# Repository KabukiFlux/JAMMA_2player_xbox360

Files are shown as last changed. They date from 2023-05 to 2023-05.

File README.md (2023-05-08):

<p align="center">
  <h1 align="center">JAMMA Xbox360 wired controller for RGBUNTU/PI/MiSTer<br>
  (cheap version, no protections)</h1>
</p>

## Table of contents

- [Description](#description)
- [Schematics](#schematics)
- [How to use](#how-to-use)
- [Bugs and feature requests](#bugs-and-feature-requests)
- [Copyright and license](#copyright-and-license)

## Description

This is intended to be a very cheap JAMMA 2 players board to USB adapter and <b> it was done during a live Twitch event (less than 4 hours)</b>.

It uses 2 pi-pico with 2 usb ports, one for the player 1 and other for the player 2, on the computer/raspberry/MiSTer side it will be automatically recognized as 2 Xbox360 wired controllers.

This board can be used as a JAMMA adapter or connected via the dirt cheap Molex KK254 connectors or the Aliexpress equivalent KF2510.

For the computer it can be connected via USB-B or the USB micro included on the PiPico

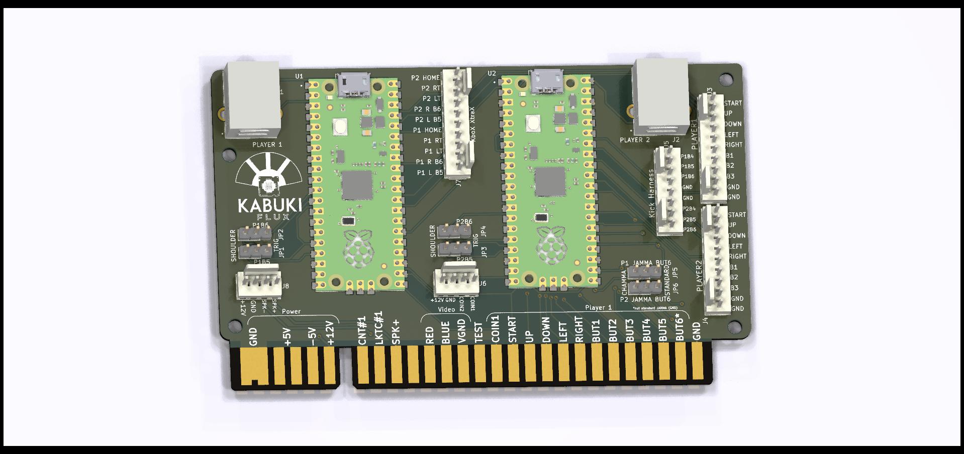
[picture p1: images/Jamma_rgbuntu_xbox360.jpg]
KiCAD_board_top


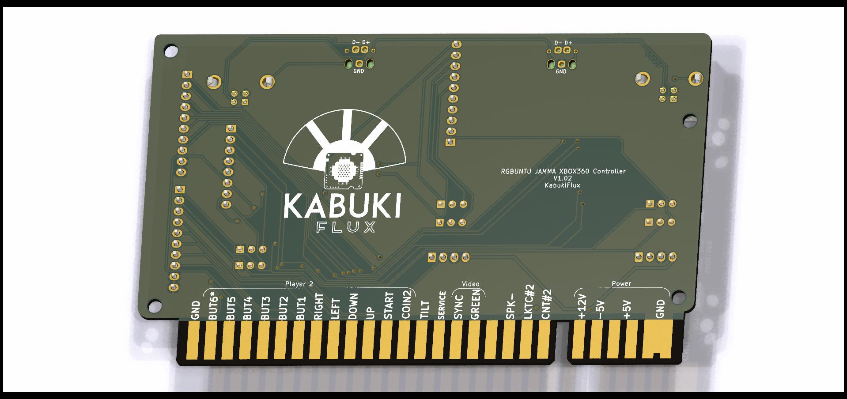
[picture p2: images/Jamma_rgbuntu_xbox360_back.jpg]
KiCAD_board_bottom


The software used for this board is the:

[FeralAI rp2040 xbox controller](https://github.com/FeralAI/GP2040)

now the project has become

[OpenStickCommunity GP2040-CE](https://github.com/OpenStickCommunity/GP2040-CE)

On the releases tab https://github.com/OpenStickCommunity/GP2040-CE/releases you can find the latest firmware GP2040-CE_X.X.X_Pico.uf2 to flash the pi pico

## Schematics

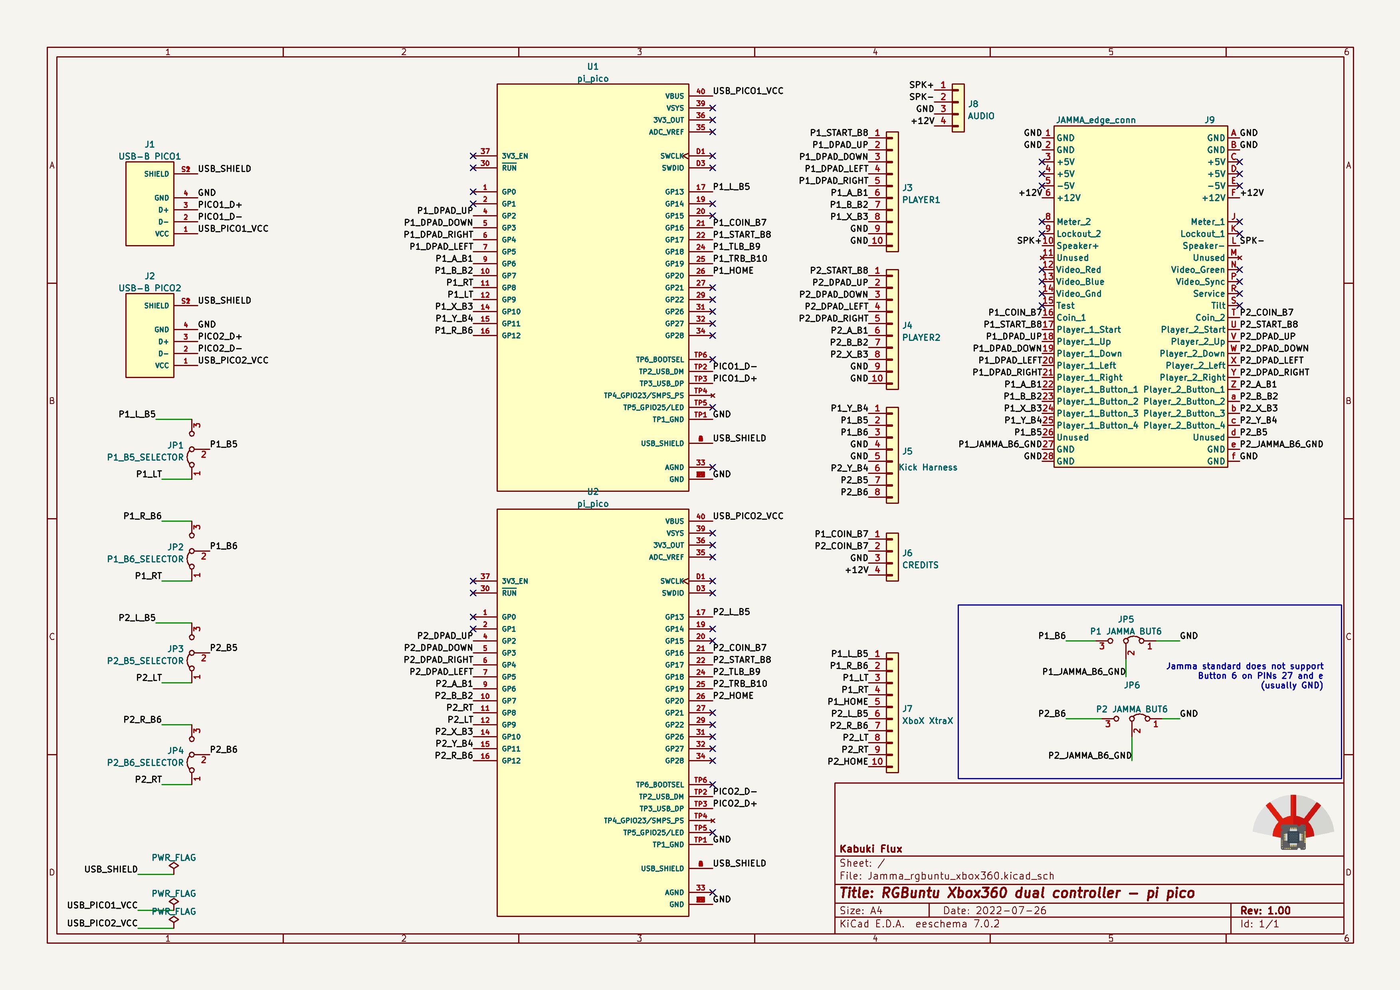
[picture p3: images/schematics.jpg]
Schematics


## How to use

1- Send to manufacture the board to JLCPCB or other PCB manufacturer. I recommend ENIG as the surface finish and Gold Fingers checked with 30º angle chamfer as well.

2- Get the components required, you can see here the Bill Of Materials [BOM](ibom.html)

3- Solder the components required by your setup (maybe you don't need audio input to the JAMMA edge or the Xtra Xbox buttons)

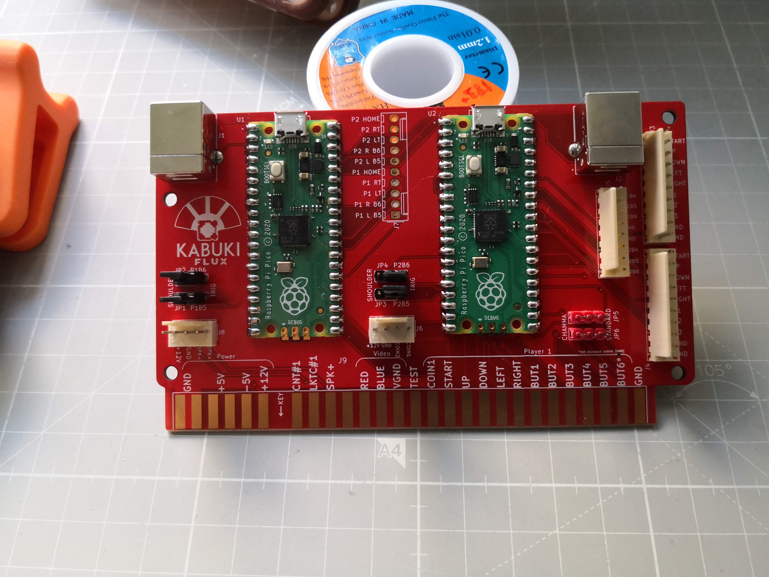
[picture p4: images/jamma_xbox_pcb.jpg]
Solder


4- On the back on the board if you want to use the USB-B connectors check that you have soldered correctly the test points called D+ and D-, it will solder directly into the test points of the PiPico the GND point is not required but recommended.

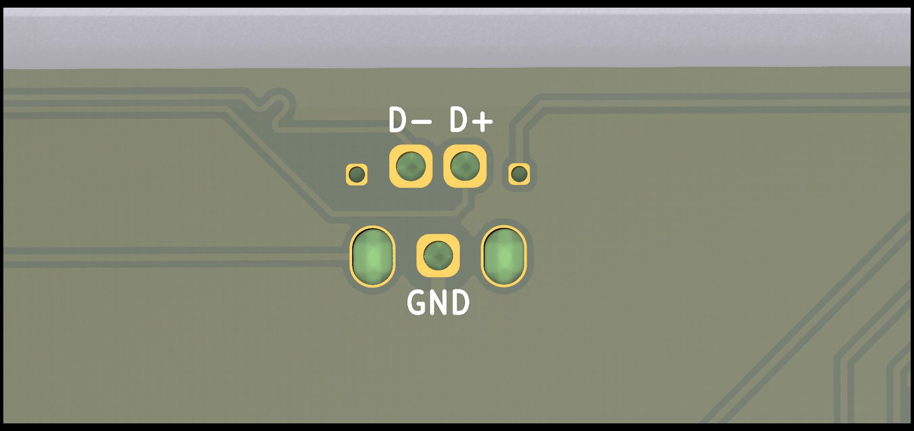
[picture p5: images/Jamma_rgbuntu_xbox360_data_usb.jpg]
Solder Usb


5- Ensure your Arcade Cabinet doesn't send 12v on the coin circuitry, a switch is only allowed here. (There are some converters, use Google)

6- Connect each PiPico to the PC and you will see a new USB drive unit appear, copy the file .uf2 from here https://github.com/OpenStickCommunity/GP2040-CE/releases into the PiPico (GP2040-CE_X.X.X_Pico.uf2) it will restart and will be recognized as a Xbox360 wired controller.

7- Connect to your arcade cabinet via JAMMA or Molex (if your JAMMA wiring is very damaged) and enjoy your PC/MiSTer/Pi setup.

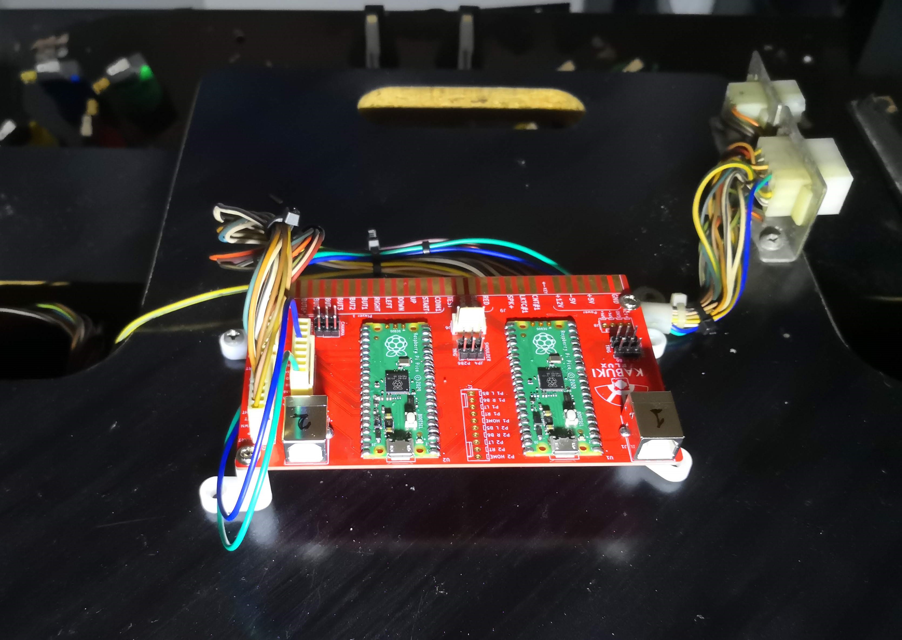
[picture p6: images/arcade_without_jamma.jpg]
Connect to Arcade Cabinet


8- If the 2nd player appears as the 1st player swap the USB cables.

### Mappings and jumpers

The default mapping is done to match the one on RGBuntu OS (15khz Ubuntu OS, use Google).

<b>If you are one of the RGBuntu developers: please, if possible, can you remap Player 2 on all systems as well, xD? (at the time of writing this only P1 is currently mapped by default)</b>.

You can see here the mapping as a Xbox360 controller (default .uf2) but everything is labeled on the silkscreen.

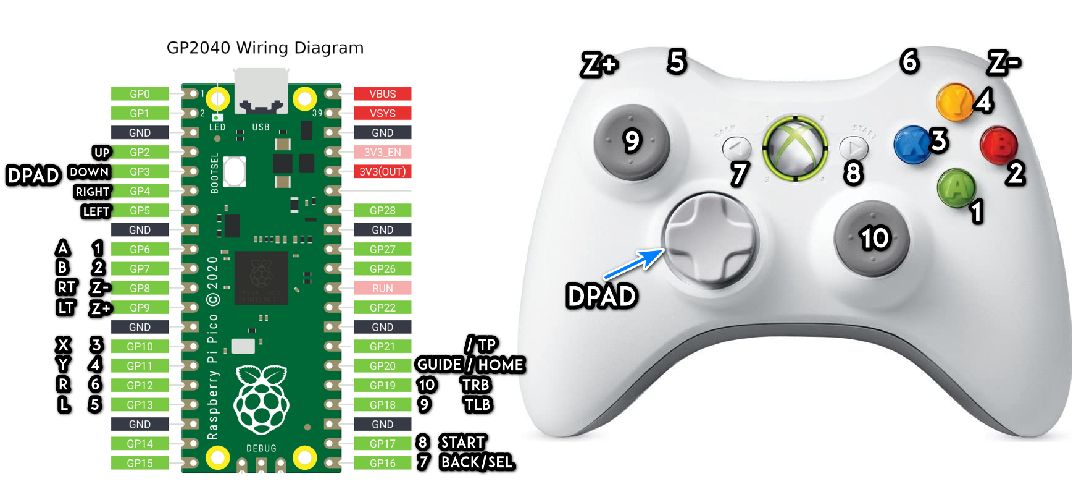
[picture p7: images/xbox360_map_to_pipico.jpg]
Xbox Mapping


- JP1, JP2, JP3 and JP4 choose the button 5 and 6 of each player to be mapped into the trigger or the shoulder buttons on the Xbox controller (I recommend the shoulder)

- JP5 and JP6 disable the button 6 of each player on the JAMMA edge to be compatible with the legacy JAMMA standard.

- J3 J4 and J5 are the Player 1, Player 2 and Kick Harness buttons respectively.

- J7 are non-standard used buttons just in case

- J6 is the dedicated coin connector, remember not to connect it if your coin mechanism sends 12vDC

- J8 is the dedicated audio input to send to the JAMMA edge in mono.

- <b>Read the documentation on https://github.com/OpenStickCommunity/GP2040-CE to see how to change the mappings in realtime like left or right stick and so.</b>

## Bugs and feature requests

Bugs and feature requests will be disabled as this is a dirty cheap example. If you want you can use it at your own risk.

### Errors

- To make it cheaper no overvoltage prevention or JAMMA wiring inductance protection has been included on the design.
- Audio speaker input has very short amperage path.

## Copyright and license

Code and documentation copyright KabukiFlux 2023. Code released under the [MIT License](https://github.com/KabukiFlux/JAMMA_2player_xbox360/blob/main/LICENSE).

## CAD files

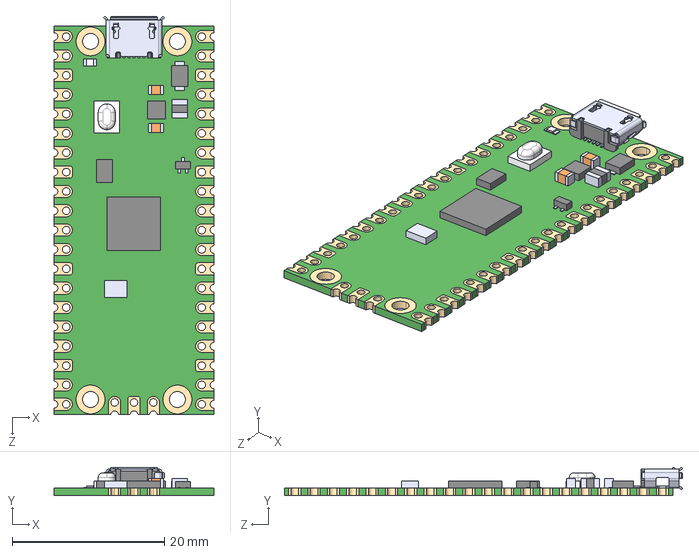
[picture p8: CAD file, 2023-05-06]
KiCAD/3D/pi_pico.step
21.0 x 3.73 x 52.3 mm

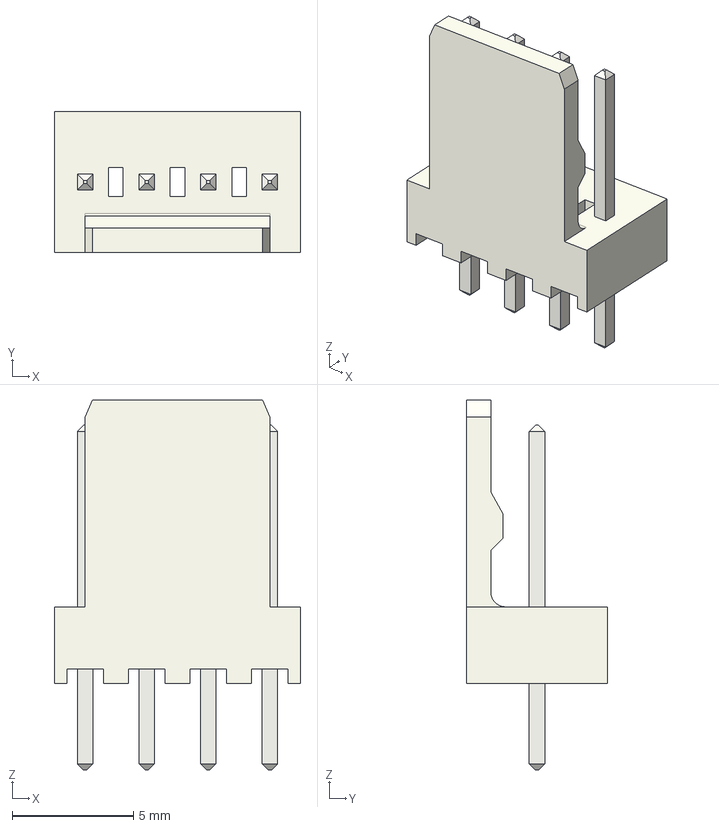
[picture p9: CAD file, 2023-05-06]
KiCAD/3D/Molex_KK-254_AE-6410-04A_1x04_P2.54mm_Vertical.step
10.2 x 5.80 x 15.3 mm

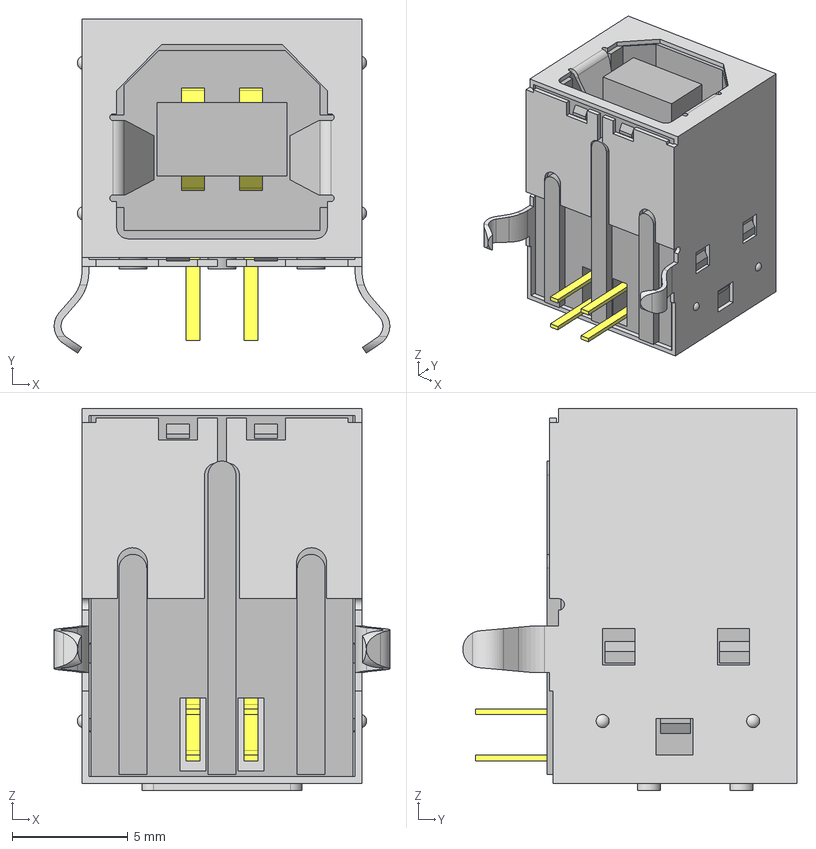
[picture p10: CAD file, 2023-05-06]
KiCAD/3D/USB-B-female.stp
14.5 x 14.4 x 16.5 mm
USB-B-S-TH_P
USB-B-S-B-TH_B
USB-B-S-TH_S

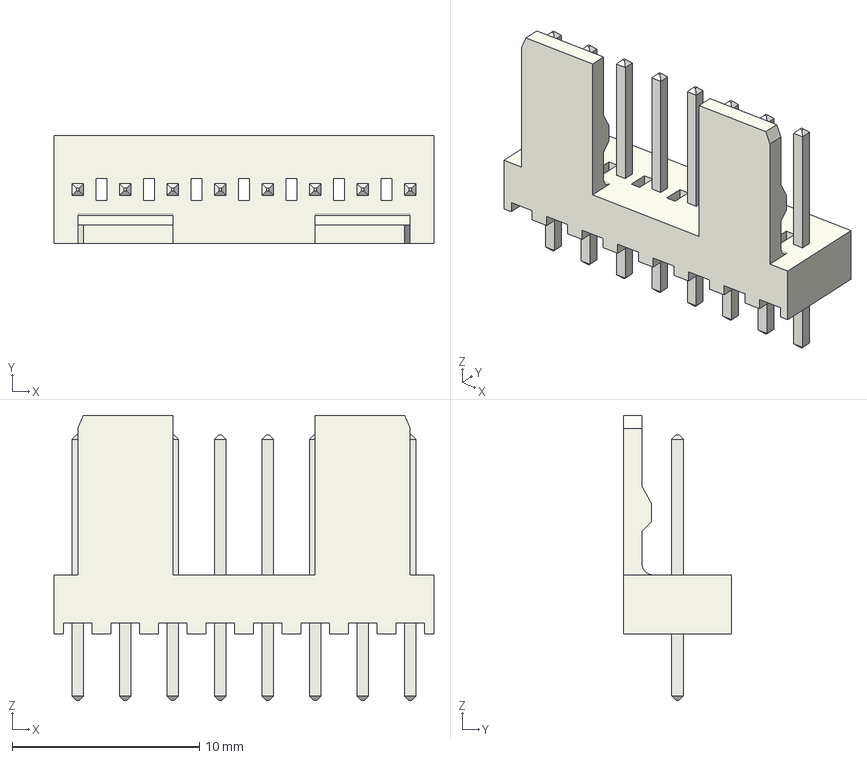
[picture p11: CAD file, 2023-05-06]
KiCAD/3D/Molex_KK-254_AE-6410-08A_1x08_P2.54mm_Vertical.step
20.3 x 5.80 x 15.3 mm

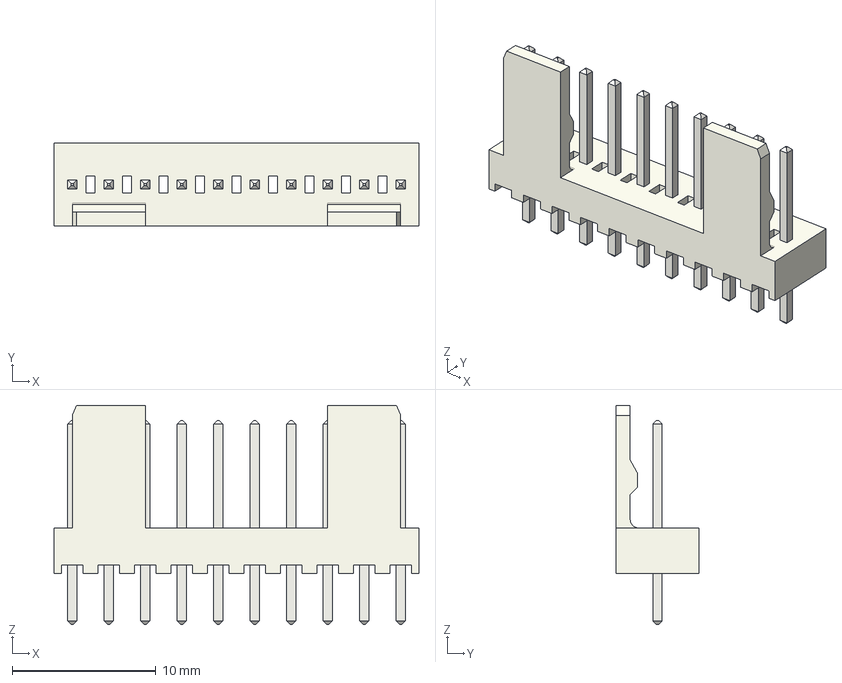
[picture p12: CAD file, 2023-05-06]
KiCAD/3D/Molex_KK-254_AE-6410-10A_1x10_P2.54mm_Vertical.step
25.4 x 5.80 x 15.3 mm

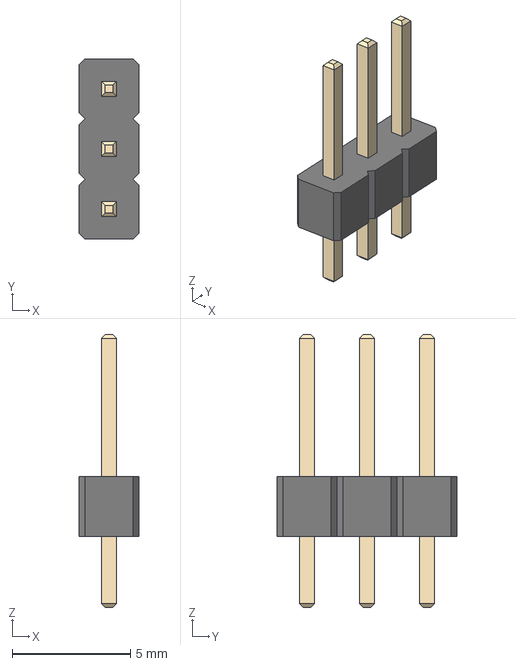
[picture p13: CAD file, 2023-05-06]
KiCAD/3D/PinHeader_1x03_P2.54mm_Vertical.step
2.54 x 7.62 x 11.5 mm

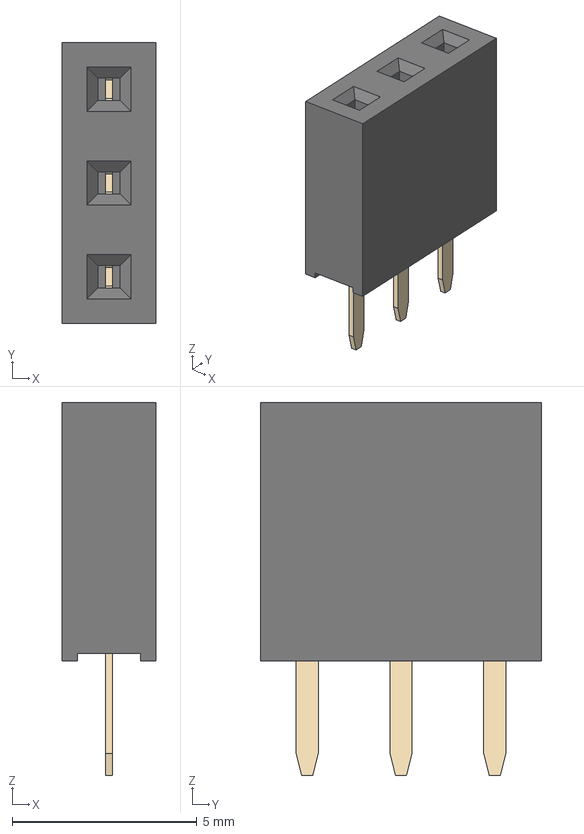
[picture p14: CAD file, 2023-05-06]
KiCAD/3D/PinSocket_1x03_P2.54mm_Vertical.step
2.54 x 7.62 x 10.1 mm

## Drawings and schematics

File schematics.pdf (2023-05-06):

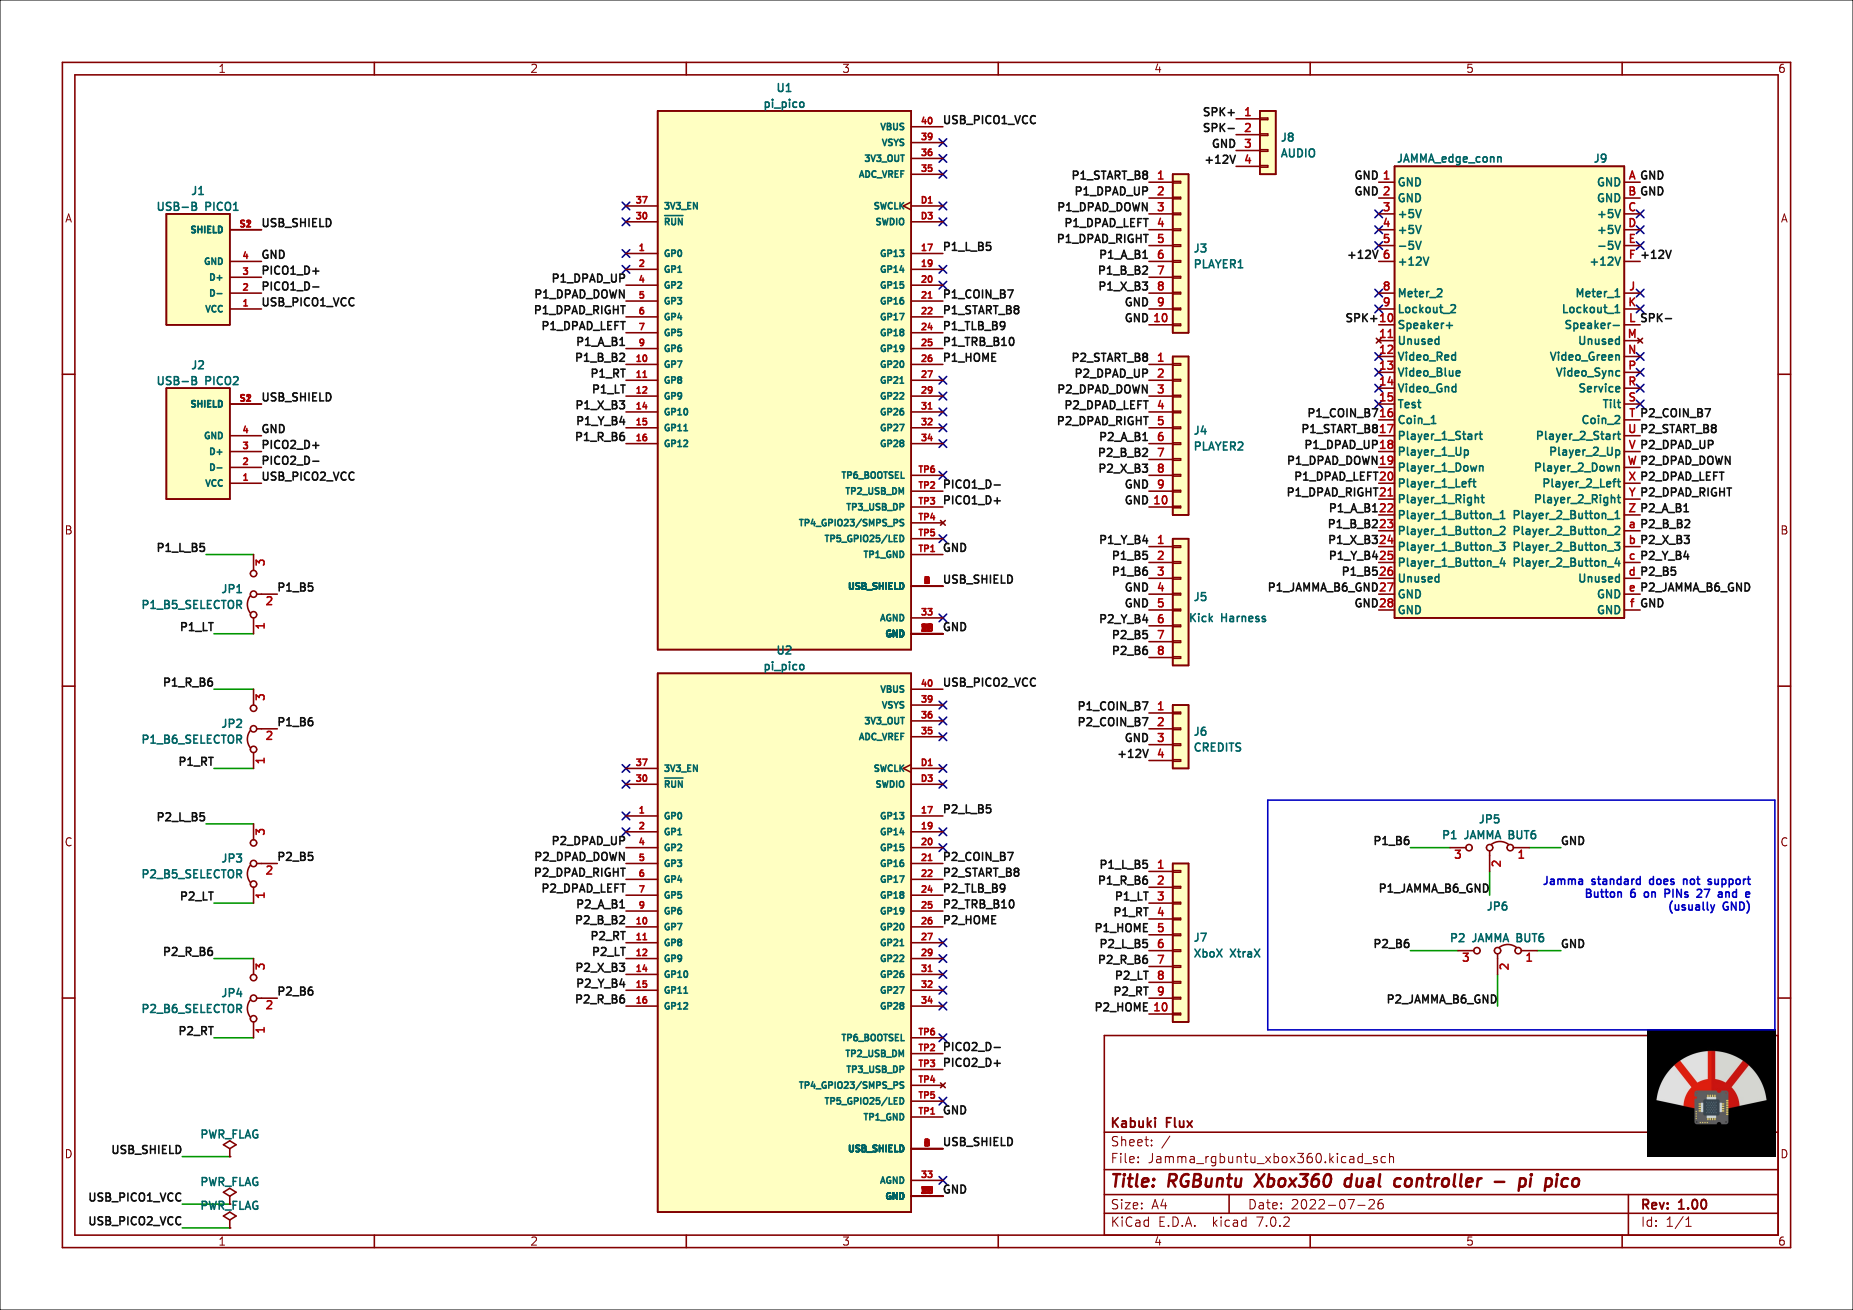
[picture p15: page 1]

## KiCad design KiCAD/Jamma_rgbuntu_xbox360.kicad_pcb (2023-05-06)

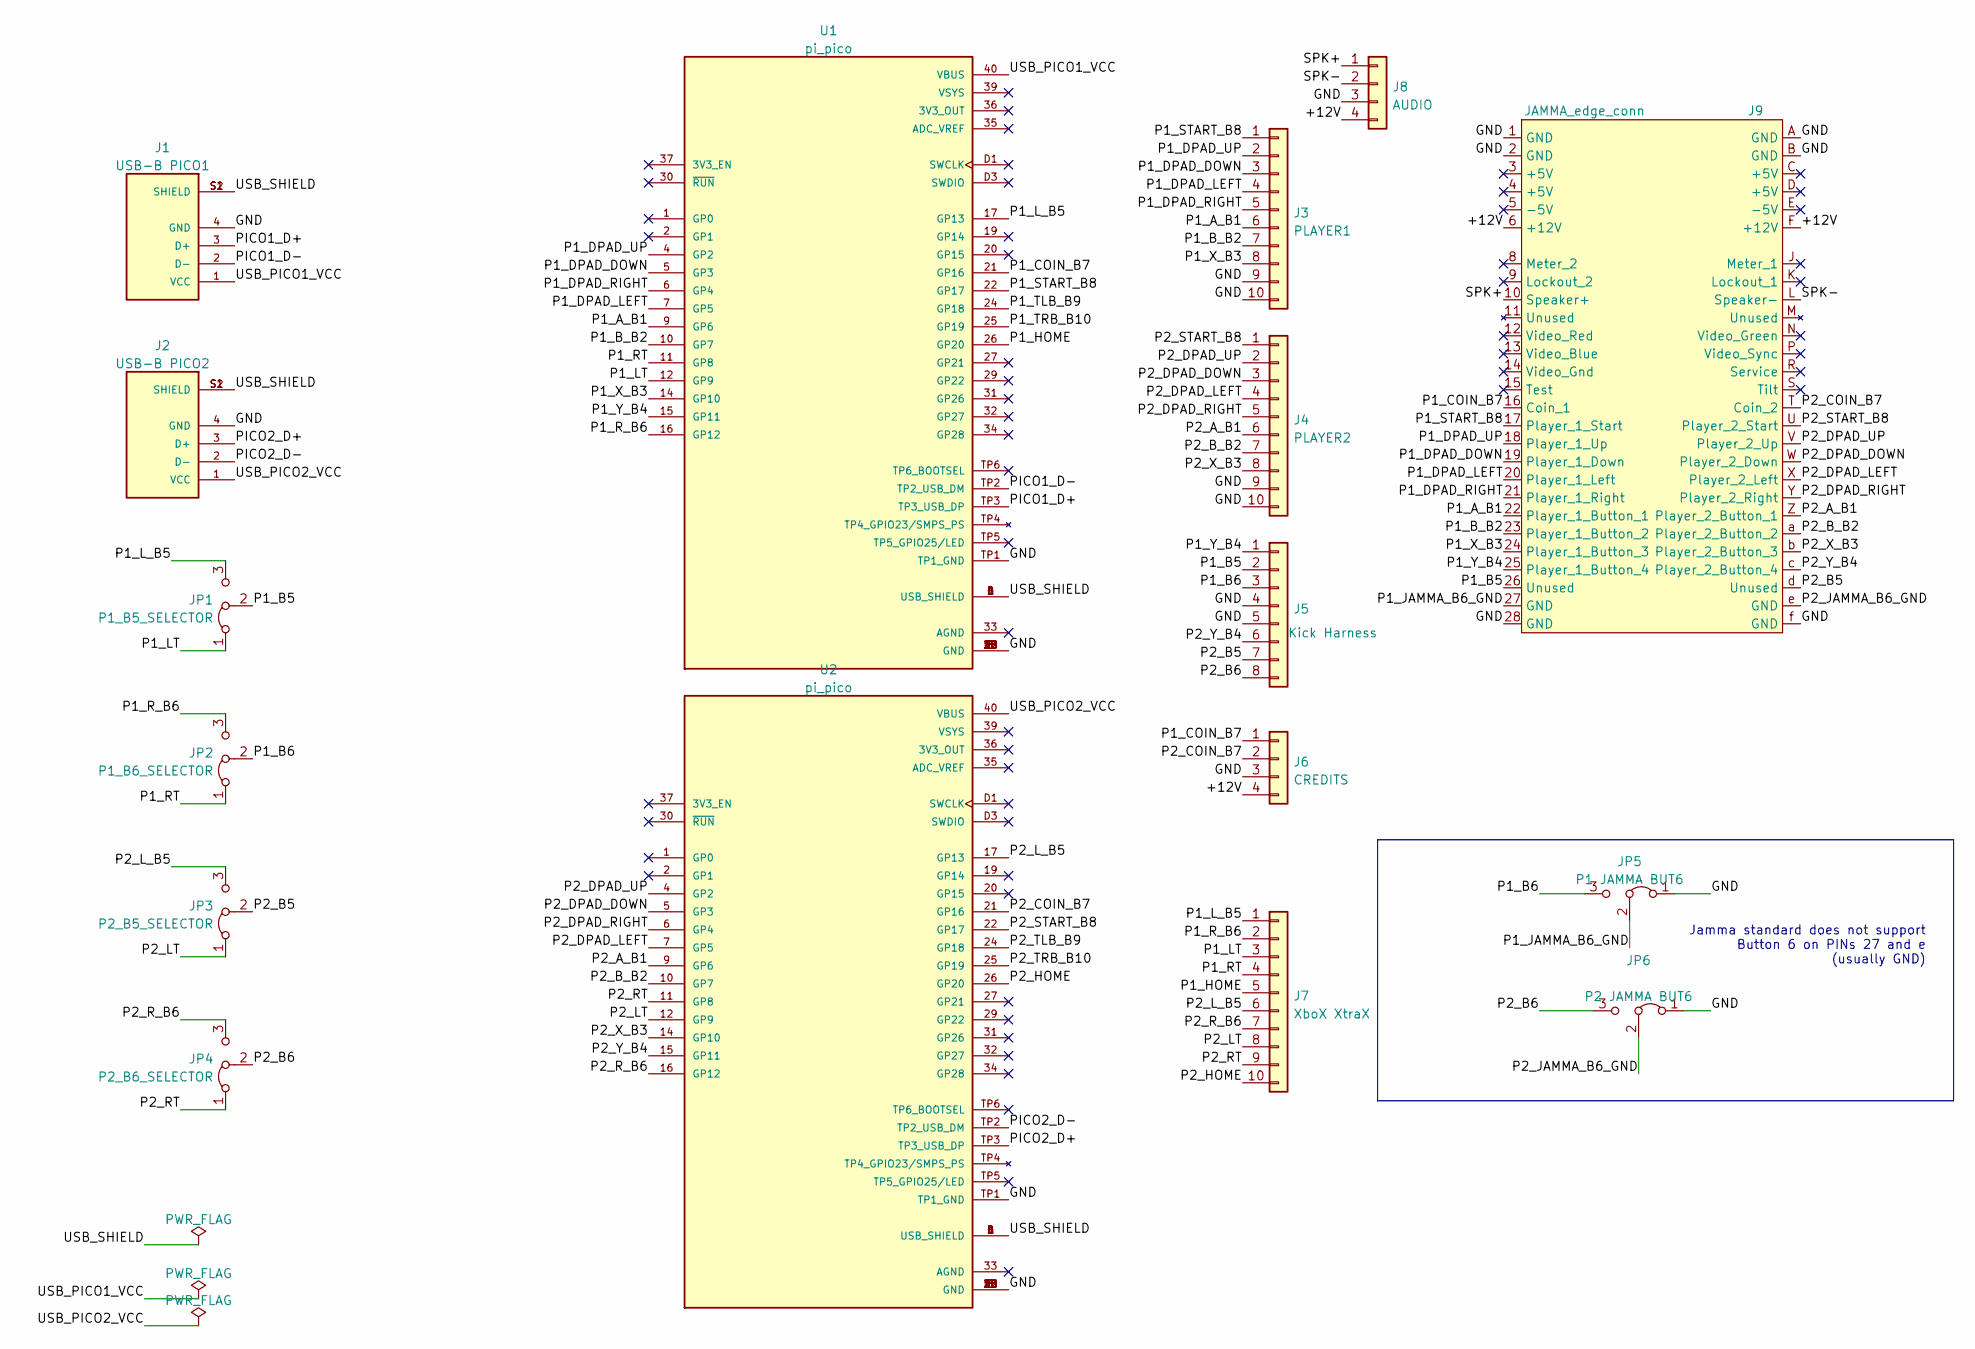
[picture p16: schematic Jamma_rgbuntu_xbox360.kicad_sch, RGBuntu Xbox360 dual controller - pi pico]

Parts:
J1: USB-B PICO1; USB-B
J2: USB-B PICO2; USB-B
J3: PLAYER1; Molex_KK-254_AE-6410-10A_1x10_P2.54mm_Vertical
J4: PLAYER2; Molex_KK-254_AE-6410-10A_1x10_P2.54mm_Vertical
J5: Kick Harness; Molex_KK-254_AE-6410-08A_1x08_P2.54mm_Vertical
J6: CREDITS; Molex_KK-254_AE-6410-04A_1x04_P2.54mm_Vertical
J7: XboX XtraX; Molex_KK-254_AE-6410-10A_1x10_P2.54mm_Vertical
J8: AUDIO; Molex_KK-254_AE-6410-04A_1x04_P2.54mm_Vertical
J9: JAMMA_edge_conn; JAMMA_edge
JP1: P1_B5_SELECTOR; PinHeader_1x03_P2.54mm_Vertical
JP2: P1_B6_SELECTOR; PinHeader_1x03_P2.54mm_Vertical
JP3: P2_B5_SELECTOR; PinHeader_1x03_P2.54mm_Vertical
JP4: P2_B6_SELECTOR; PinHeader_1x03_P2.54mm_Vertical
JP5: P1 JAMMA BUT6; PinSocket_1x03_P2.54mm_Vertical
JP6: P2 JAMMA BUT6; PinSocket_1x03_P2.54mm_Vertical
U1, U2: pi_pico; pi-pico; PARTREV 1.6

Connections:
/+12V: J6.4, J8.4, J9.6 (+12V), J9.F (+12V)
/GND: J1.4 (GND), J2.4 (GND), J3.9, J3.10, J4.9, J4.10, J5.4, J5.5, J6.3, J8.3, J9.1 (GND), J9.2 (GND), J9.28 (GND), J9.A (GND), J9.B (GND), J9.f (GND), JP5.1 (A), JP6.1 (A), U1.3 (GND), U1.8 (GND), U1.13 (GND), U1.18 (GND), U1.23 (GND), U1.28 (GND), U1.38 (GND), U1.D2 (GND), U1.TP1 (TP1_GND), U2.3 (GND), U2.8 (GND), U2.13 (GND), U2.18 (GND), U2.23 (GND), U2.28 (GND), U2.38 (GND), U2.D2 (GND), U2.TP1 (TP1_GND)
/P1_A_B1: J3.6, J9.22 (Player_1_Button_1), U1.9 (GP6)
/P1_B5: J5.2, J9.26 (Unused), JP1.2 (C)
/P1_B6: J5.3, JP2.2 (C), JP5.3 (B)
/P1_B_B2: J3.7, J9.23 (Player_1_Button_2), U1.10 (GP7)
/P1_COIN_B7: J6.1, J9.16 (Coin_1), U1.21 (GP16)
/P1_DPAD_DOWN: J3.3, J9.19 (Player_1_Down), U1.5 (GP3)
/P1_DPAD_LEFT: J3.4, J9.20 (Player_1_Left), U1.7 (GP5)
/P1_DPAD_RIGHT: J3.5, J9.21 (Player_1_Right), U1.6 (GP4)
/P1_DPAD_UP: J3.2, J9.18 (Player_1_Up), U1.4 (GP2)
/P1_HOME: J7.5, U1.26 (GP20)
/P1_JAMMA_B6_GND: J9.27 (GND), JP5.2 (C)
/P1_LT: J7.3, JP1.1 (A), U1.12 (GP9)
/P1_L_B5: J7.1, JP1.3 (B), U1.17 (GP13)
/P1_RT: J7.4, JP2.1 (A), U1.11 (GP8)
/P1_R_B6: J7.2, JP2.3 (B), U1.16 (GP12)
/P1_START_B8: J3.1, J9.17 (Player_1_Start), U1.22 (GP17)
/P1_TLB_B9: U1.24 (GP18)
/P1_TRB_B10: U1.25 (GP19)
/P1_X_B3: J3.8, J9.24 (Player_1_Button_3), U1.14 (GP10)
/P1_Y_B4: J5.1, J9.25 (Player_1_Button_4), U1.15 (GP11)
/P2_A_B1: J4.6, J9.Z (Player_2_Button_1), U2.9 (GP6)
/P2_B5: J5.7, J9.d (Unused), JP3.2 (C)
/P2_B6: J5.8, JP4.2 (C), JP6.3 (B)
/P2_B_B2: J4.7, J9.a (Player_2_Button_2), U2.10 (GP7)
/P2_COIN_B7: J6.2, J9.T (Coin_2), U2.21 (GP16)
/P2_DPAD_DOWN: J4.3, J9.W (Player_2_Down), U2.5 (GP3)
/P2_DPAD_LEFT: J4.4, J9.X (Player_2_Left), U2.7 (GP5)
/P2_DPAD_RIGHT: J4.5, J9.Y (Player_2_Right), U2.6 (GP4)
/P2_DPAD_UP: J4.2, J9.V (Player_2_Up), U2.4 (GP2)
/P2_HOME: J7.10, U2.26 (GP20)
/P2_JAMMA_B6_GND: J9.e (GND), JP6.2 (C)
/P2_LT: J7.8, JP3.1 (A), U2.12 (GP9)
/P2_L_B5: J7.6, JP3.3 (B), U2.17 (GP13)
/P2_RT: J7.9, JP4.1 (A), U2.11 (GP8)
/P2_R_B6: J7.7, JP4.3 (B), U2.16 (GP12)
/P2_START_B8: J4.1, J9.U (Player_2_Start), U2.22 (GP17)
/P2_TLB_B9: U2.24 (GP18)
/P2_TRB_B10: U2.25 (GP19)
/P2_X_B3: J4.8, J9.b (Player_2_Button_3), U2.14 (GP10)
/P2_Y_B4: J5.6, J9.c (Player_2_Button_4), U2.15 (GP11)
/PICO1_D+: J1.3 (D+), U1.TP3 (TP3_USB_DP)
/PICO1_D-: J1.2 (D-), U1.TP2 (TP2_USB_DM)
/PICO2_D+: J2.3 (D+), U2.TP3 (TP3_USB_DP)
/PICO2_D-: J2.2 (D-), U2.TP2 (TP2_USB_DM)
/SPK+: J8.1, J9.10 (Speaker+)
/SPK-: J8.2, J9.L (Speaker-)
/USB_PICO1_VCC: J1.1 (VCC), U1.40 (VBUS)
/USB_PICO2_VCC: J2.1 (VCC), U2.40 (VBUS)
/USB_SHIELD: J1.S1 (SHIELD), J1.S2 (SHIELD), J2.S1 (SHIELD), J2.S2 (SHIELD), U1.A (USB_SHIELD), U1.B (USB_SHIELD), U1.C (USB_SHIELD), U1.D (USB_SHIELD), U2.A (USB_SHIELD), U2.B (USB_SHIELD), U2.C (USB_SHIELD), U2.D (USB_SHIELD)

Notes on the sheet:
Jamma standard does not support Button 6 on PINs 27 and e (usually GND)

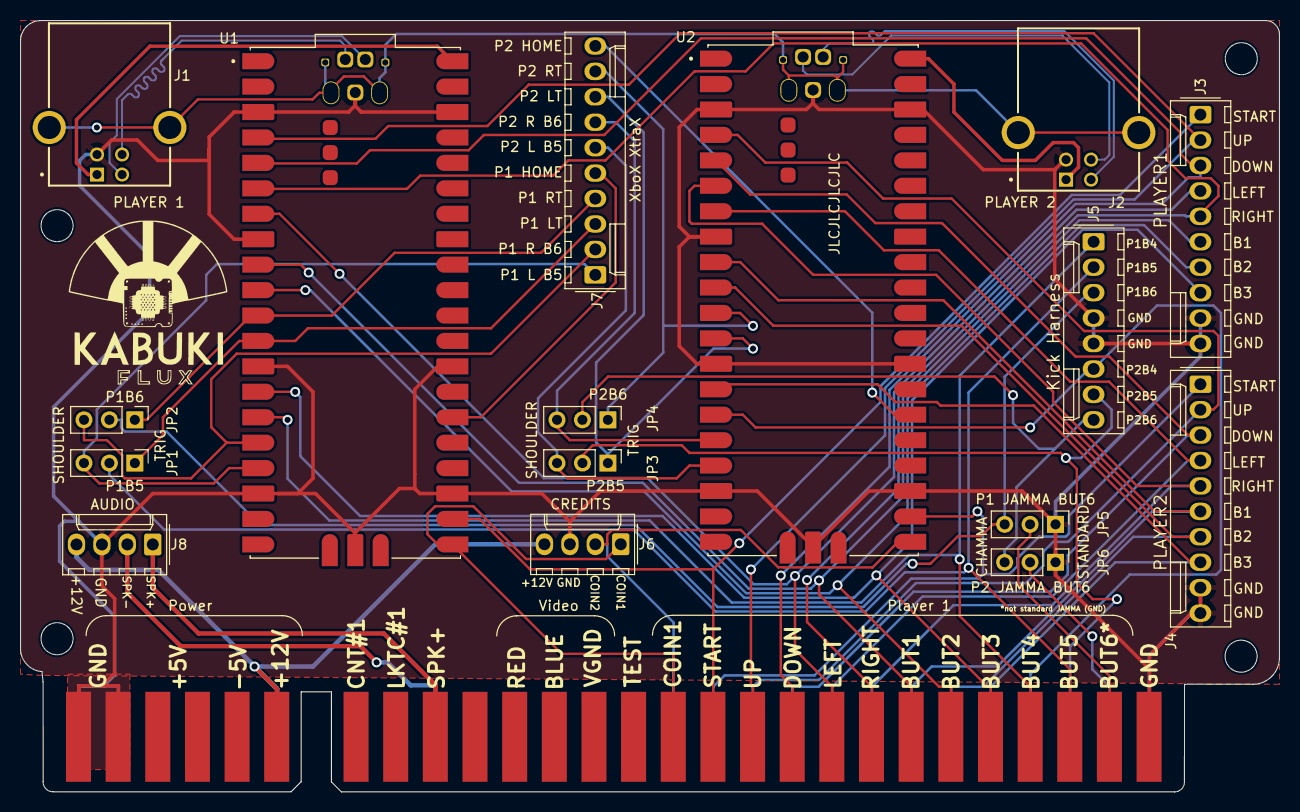
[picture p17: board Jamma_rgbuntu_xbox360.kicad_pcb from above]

Board: 2 copper layers, 125.7 x 77.0 mm, 22 parts (0 on the bottom side), 47 nets.

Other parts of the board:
G1: LOGO; LogoKabuki_18mm
HOLE1, HOLE2, HOLE3, HOLE4: MountingHole_3.2mm_M3

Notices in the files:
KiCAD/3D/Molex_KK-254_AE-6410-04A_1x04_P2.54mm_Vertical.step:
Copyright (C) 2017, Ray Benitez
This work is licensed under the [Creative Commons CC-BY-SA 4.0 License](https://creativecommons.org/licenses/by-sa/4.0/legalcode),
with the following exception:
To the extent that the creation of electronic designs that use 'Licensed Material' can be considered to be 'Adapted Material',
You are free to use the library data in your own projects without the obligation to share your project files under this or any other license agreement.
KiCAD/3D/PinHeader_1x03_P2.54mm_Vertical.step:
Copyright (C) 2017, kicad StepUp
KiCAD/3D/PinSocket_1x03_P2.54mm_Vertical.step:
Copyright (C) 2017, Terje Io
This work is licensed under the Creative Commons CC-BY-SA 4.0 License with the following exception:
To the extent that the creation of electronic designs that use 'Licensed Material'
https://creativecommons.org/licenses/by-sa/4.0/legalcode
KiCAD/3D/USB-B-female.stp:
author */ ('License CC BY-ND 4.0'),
